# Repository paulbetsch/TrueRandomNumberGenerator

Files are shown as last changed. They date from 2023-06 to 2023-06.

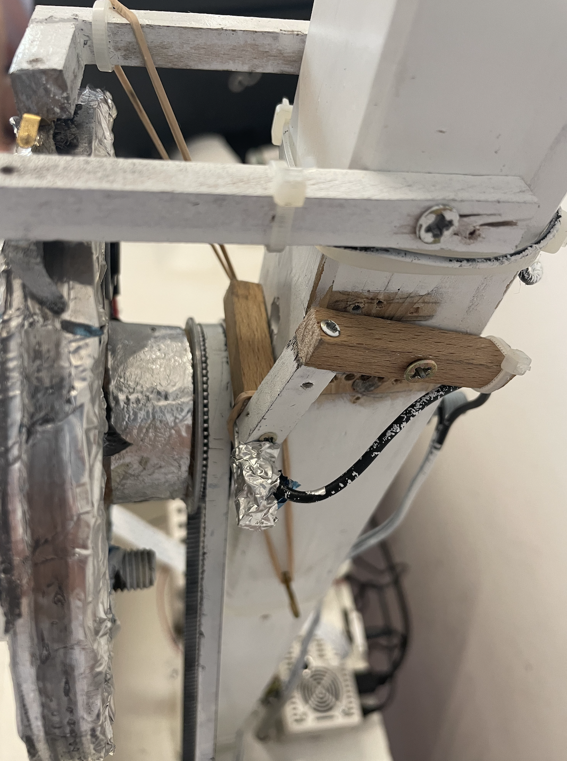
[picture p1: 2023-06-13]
TRNG_Pendel/Ressources/Construction/Pictures/Image20.jpeg

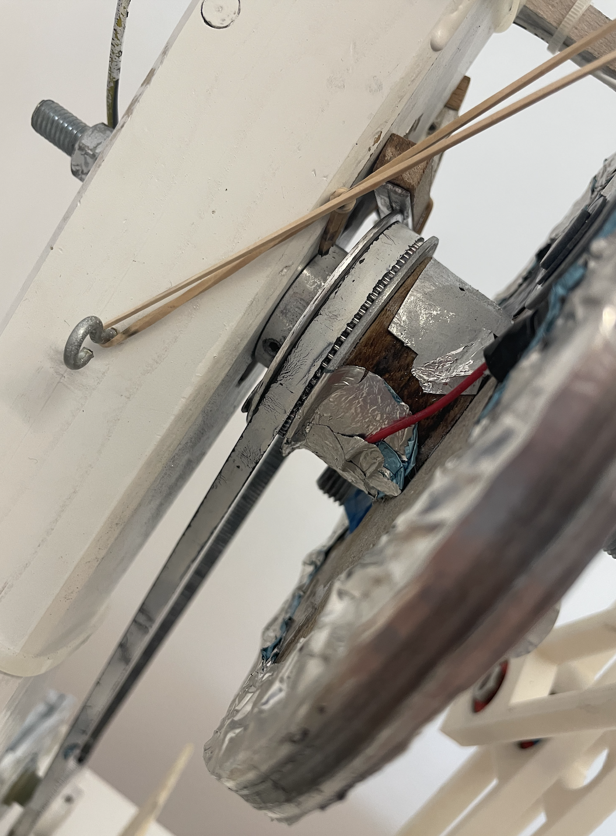
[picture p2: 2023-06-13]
TRNG_Pendel/Ressources/Construction/Pictures/Image18.jpeg

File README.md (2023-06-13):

# TRNG (True Random Number Generator)

## About
This repository includes all scripts and files which we use to develop a True Random Number Generator. There is a directory for each tool, we developed to help us. The whole Software solution can be found in the directory called "TRNG-Pendel".

## Requirements for setup
### Basic Setup:
- Tri Pendulum with a black square at the end of the thrid pendulum arm
- Raspberry Pi
- Raspberry Pi Camera Module
### Advanced Setup:
- Same components as for the basic setup and the following in addition:
- 12V electric motor
- 24V electric lifiting magnet
- Relay which can control up to 24V
- Jumper cables
- Power sources for motor, magnet and Raspberry Pi

## Requirements for Installation
- \>= [Python 3.9](https://www.python.org/downloads/release/python-390/)
- Any IDE you prefer, e. g. PyCharm, VS Code, Python IDE
- Git CLI to get the code onto the Raspberry Pi

## Installation
- use command : `git clone https://github.com/paulbetsch/TrueRandomNumberGenerator.git`
- than follow the instructions for [setting up the frontend](./FrontEnd/README.md)
- To setup the API follow these [instructions](./TRNG_API/README.md)
- When both servers are running and you can reach them you are ready to generate!

## Code Style
- Always **comment your code** with a short explanation of what it does.
- Make sure that at least one team member understand your comments.
- Global variables should be written in upper case with underlines instead of spaces e.g TEST_VARIABLE.
- Local variables should be written in camelCase.
- Function names should be written in PascalCase except the main function which is called: `__main__()`.
- If possible divide your code into multiple python files.
- If you have **multiple python files**, make sure you have **one start file**, which should be called `__init__.py`.
- Any other python files should be written in PascalCase excluding the start file.
- You have to **write a README.md file**, which explains everything/script/file contained in the directory.
- The code should always work **without any external Data**.
- All **filepaths must be relative**, so that the code works on every single PC.

## Team
- Carlo Bauer
- Paul Betsch
- Lukas Siegle
- Marina Göppel 
- Carsten Michel
-  Stefan Kleinhenz Leiva

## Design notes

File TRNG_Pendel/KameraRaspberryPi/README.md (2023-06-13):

# TRNG Live Image Capturing

## About
This repository includes code snippets, which we currently use on capturing live images from a RaspberryPi camera.

## Requirements
- These Scripts can only be run on the Raspberry Pi due to specific libraries

## Scripts
- __ObjectTracker__: The PendelManger class controls the interaction between the ObjectTracker and itself through shared variables. While a specific shared variable is set to true, the ObjectTracker continuously tracks black contours captured by a connected camera. If an error occurs during tracking, an error event is triggered and set as another shared variable, which can be accessed by the PendelManger. The PendelManger has the ability to set the first shared variable to false, effectively stopping the ObjectTracker. Additionally, the ObjectTracker generates random bits with the tracked Contours and writes them into a shared list with the PendelManger.

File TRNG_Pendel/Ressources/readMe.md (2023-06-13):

The files contained in this folder are 3D models for the TRNG. The files contain casings for a Raspberry Pi 3b+, anrelay, and a camera as well as a pendulum arm. The .stl files can be opened and edited with Autodesk Fusion 360. All models should be printed using pearl white PLA printing material.

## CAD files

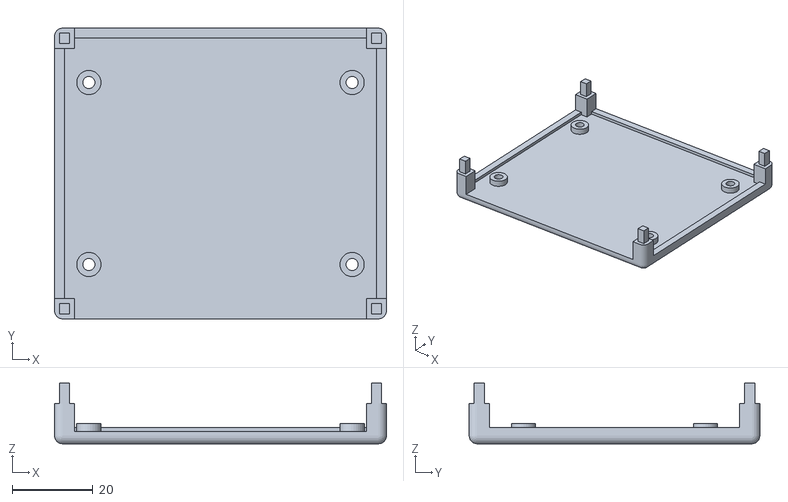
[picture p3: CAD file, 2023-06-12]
TRNG_Pendel/Ressources/3DModels/Relay_Mounting_Bottom.stl
82.1 x 71.9 x 15.0

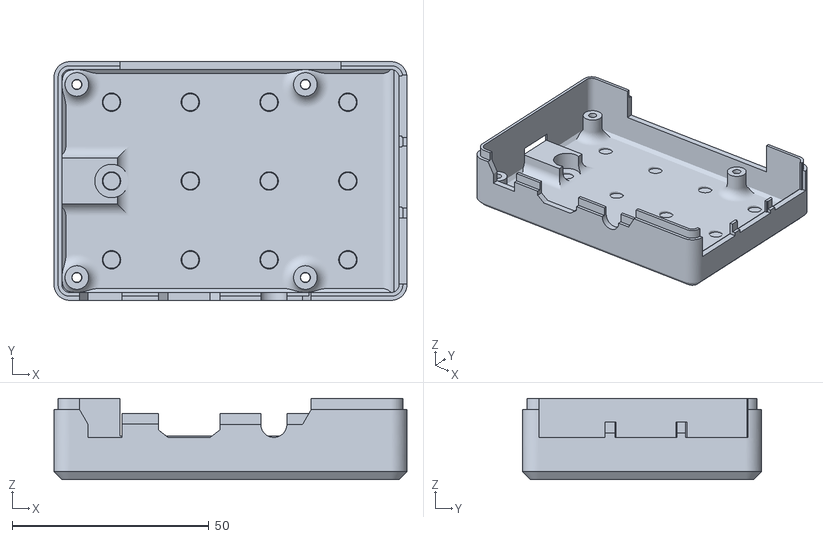
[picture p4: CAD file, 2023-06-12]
TRNG_Pendel/Ressources/3DModels/Raspberry_Pi_Mounting_Bottom.stl
89.6 x 60.6 x 20.6

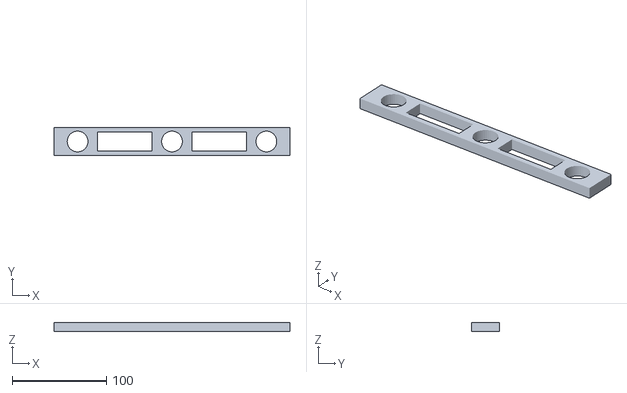
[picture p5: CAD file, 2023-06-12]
TRNG_Pendel/Ressources/3DModels/Pendulum_Arm.stl
250.0 x 30.0 x 10.0

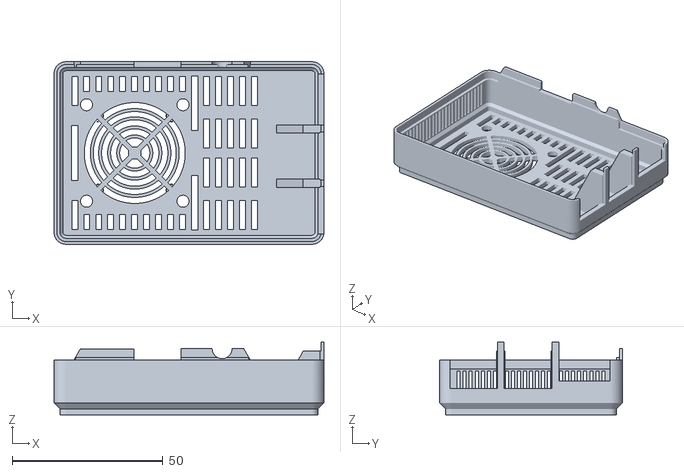
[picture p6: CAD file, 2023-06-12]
TRNG_Pendel/Ressources/3DModels/Raspberry_Pi_Mounting_Top.stl
89.6 x 60.6 x 24.2

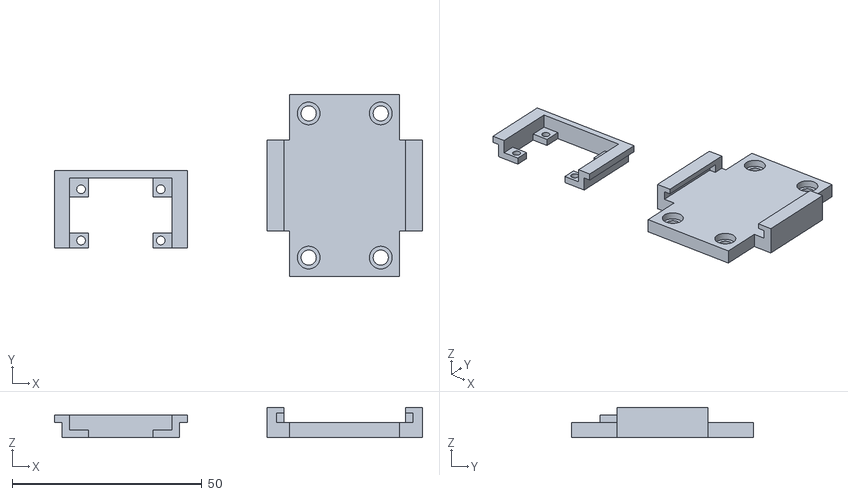
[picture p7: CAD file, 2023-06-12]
TRNG_Pendel/Ressources/3DModels/Camera_Mounting.stl
97.0 x 48.0 x 8.00

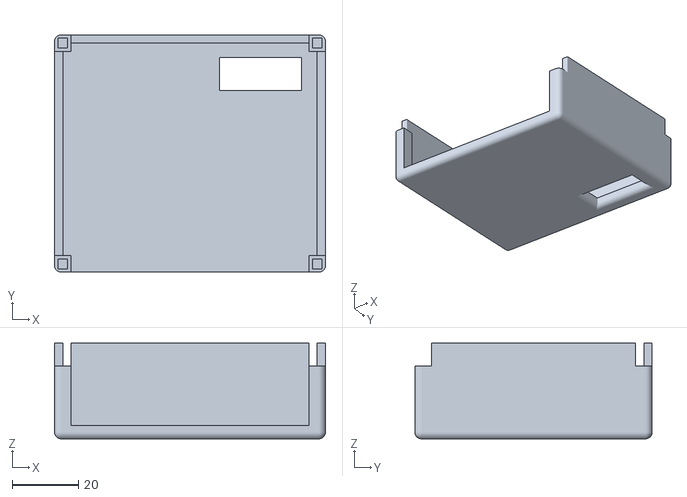
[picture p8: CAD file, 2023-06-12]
TRNG_Pendel/Ressources/3DModels/Relay_Mounting_Top.stl
82.1 x 71.9 x 29.0

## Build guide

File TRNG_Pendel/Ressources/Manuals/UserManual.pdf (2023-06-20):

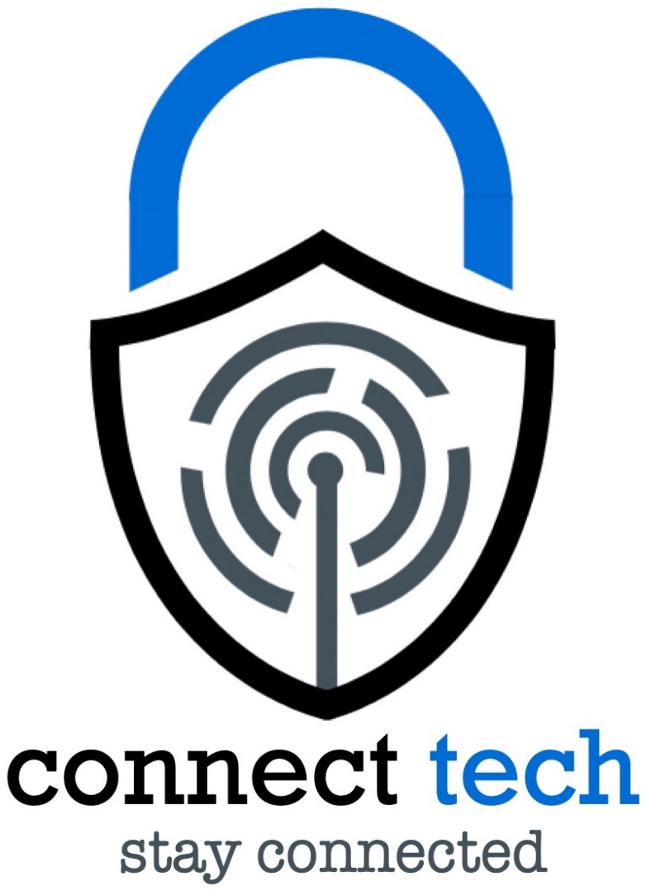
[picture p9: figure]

# User Manual Project Semester 2023

Carlo Bauer
Paul Betsch
Marina G¨oppel
Stefan Kleinhenz Leiva
Carsten Michel
Lukas Siegle

June 14, 2023

1

Project documentation

## Contents

1 Intended Use | 2
2 Usage | 3
3 Troubleshooting | 6

1

Project documentation

## 1 Intended Use

The intended use of this Pendulum is to be a True random bits Generator. A True random bits Generator uses a physical noise source to generate true random bits. The API allows for the reg-ulation of the number of bits the numbers should possess and the quantity in which they should be generated. The random bits can then be used for various applications, such as cryptography, simulation or scientific research.

This prototype of a True random bits Generator(TRNG) was invented and developed in the context of our project semester during the summer of 2023 at the University of Applied Science Mannheim.

### 1.1 Warnings

i. With this construction there is electricity in most parts. It is recommended to pull all power supplies before you work with or repair the prototype.

ii. All cables are lined with a cable conduit. Please refrain from taking them out and touching them.

iii. While the prototype is active the pendulum swings in a circular motion. Please stay at least 1m away from the pendulum to avoid getting hit.

iv. While the prototype is initialized, do not interfere in any way with the sampling process.

v. Please do not touch any cables or circuit boards integrated in the prototype.

vi. Use the prototype only with a good light setup to ensure no shadows are being captured by the camera. Shadows can massively interfere with the quality of the random bits.

2

Project documentation

## 2 Usage

### 2.1 General REST API Endpoints

This table covers various endpoints and their paths for accessing a random number generator in general. The random number generator produces HEX-encoded bit arrays as its output, with leading zeros added if necessary. To add leading zeros was explicitly wished by the client, we strongly advise against adding leading zeros to an hex-encoded random number in a normal context.

Endpoints | Path | Responses | Definition
GetRandomNums | /randomNum/getRandom | 200 | successful operation; HEX-encoded bit arrays (with leading zero if required)
| | 432 | system not ready; try init
| | 500 | data generation failed; check noise source
InitRandomNums | /randomNum/init | 200 | successful operation; random bits generator is ready and random bits can be requested
| | 409 | system already running
| | 500 | functionality not given; check hardware
| | 555 | unable to initialize the random bits generator within a timeout of 60 seconds
ShutdownRandomNums | /randomNum/shutdown | 200 | successful operation; random bits generator has been set to ’standby mode’
| | 409 | system already shutdown

### 2.2 How to use the REST API

A REST API allows different software applications to communicate and exchange data over the internet using standardized HTTP protocols. Our REST API provides all the necessary functionalities and logic responsible for the aforementioned requests and the initialization of the TRNG and its associated components.
To use the REST API you can choose a HTTP client of your choice e.g. Postman or Curl. In the following enumaration we explain how to interact with the API using Curl.
1. First of all it’s necessary to initialize the TRNG with the following command:

curl https://172.16.78.60:5520/trng/randomNum/init

3

Project documentation

2. If the request returns a status code 200 you can start generating random bits. To get random bits use following command:

curl https://172.16.78.60:5520/trng/randomNum/getRandom?quantity=16numBits=64

3. After you recieved your random bits it is possible to put the TRNG into standby mode by sending the following request:

curl https://172.16.78.60:5520/trng/randomNum/shutdown

### 2.3 Frontend

In order to have an easy access and control for the REST API, we have got as requirement to implement a frontend webpage. Accordingly, we have developed and implemented a user-friendly interface in order to access and interact with the REST-API´s functionalities.

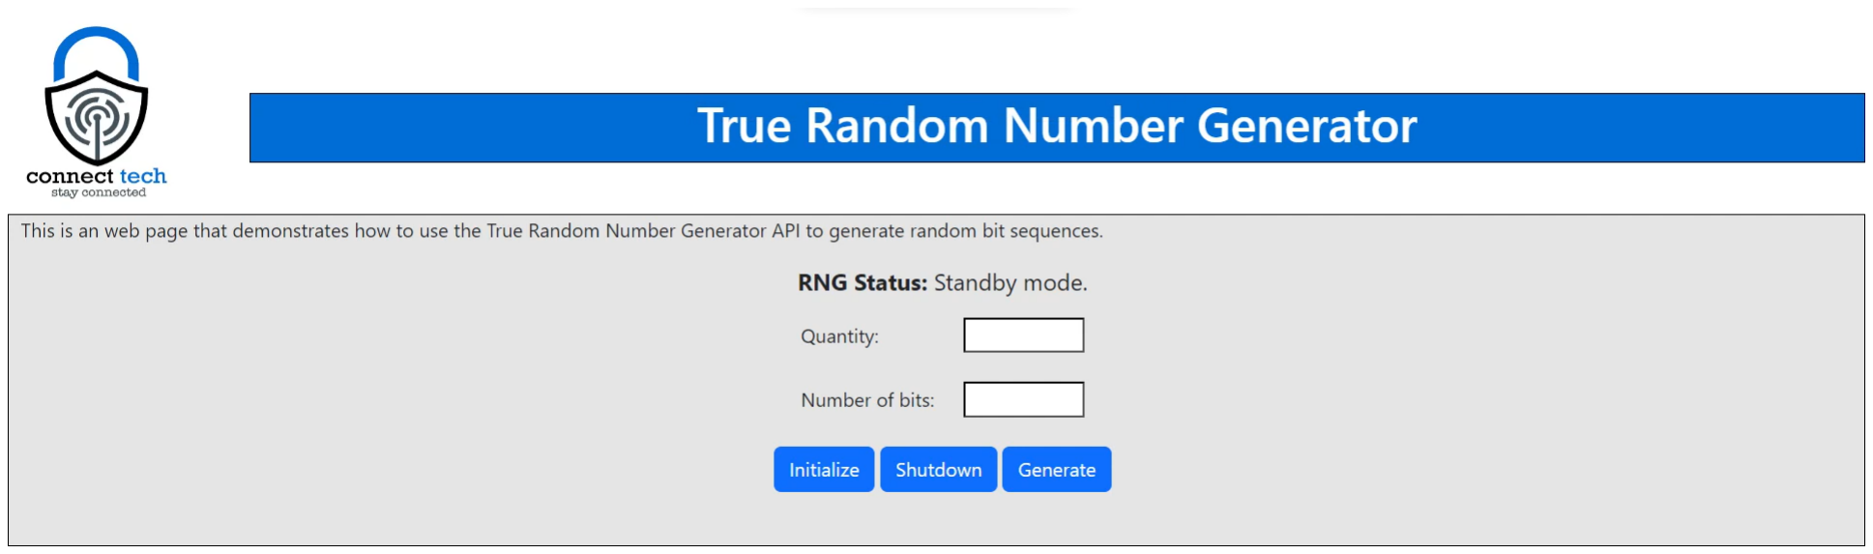
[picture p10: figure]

Figure 1: Webpage

- Quatity: This text box is intended for specifying the desired number of bits to be generated. It only accepts positive numbers as input.
- Number of bits: This text box is for specifying the length of the bits to be generated. It only accepts positive numbers as input.
- Initialize: This button is responsible for the aforementioned init request. Once the button is clicked, it will initialize the pendulum and its associated components.
- Shutdown: This button is responsible for the aforementioned shutdown request. Once the button is pressed, it will shut down the pendulum and its associated components.
- Generate: This button is responsible for initiating the getRandom request mentioned earlier. When the button is clicked, bits will be generated based on the input from two text boxes. The user can specify the desired number of bits and their desired length. Once the bits are generated, they will be displayed in a table format.

4

Project documentation

The RNG Status text provides the current state of the pendulum, indicating whether it is initialized, shut down, or generating bits.

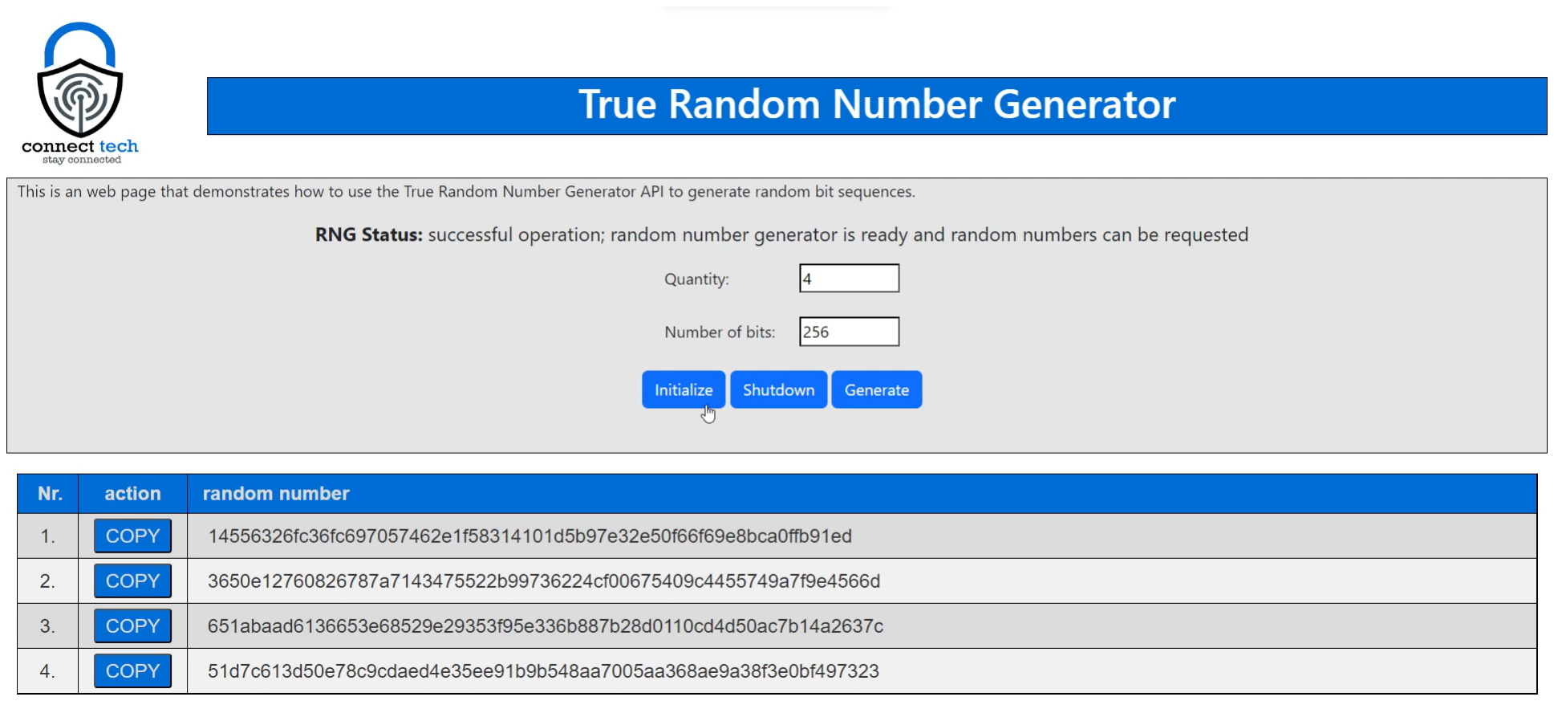
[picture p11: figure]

Figure 2: Webpage - Output example

5

Project documentation

## 3 Troubleshooting

Component | Problem | Solution
Magnet | Sliding contacts lost connection | Push contacts back on the tracks
| Sliding contact is defect | Exchange sliding contact
| Cable from Magnet to sliding tracks is defect | Glue back cable onto tracks
| Power supply is defect | Exchange power supply
| Lifting magnet is defect | Exchange magnet
Relay | Relay is defect | Unscrew cables and screw them back into place

Check connection between
relay and Raspberry Pi
Motor | Cables are loose | Reconnect cables
| Strap is broken | Exchange strap
| Strap is not in place | Put strap back in place
| None of the above worked | Check connection between relay and Raspberry Pi

Check power source
Exchange motor
Pendulum | Pendulum arm is broken | Exchange with 3D printed arm
Camera | No connection | Check cable on Raspberry Pi and on camera

Exchange camera

6

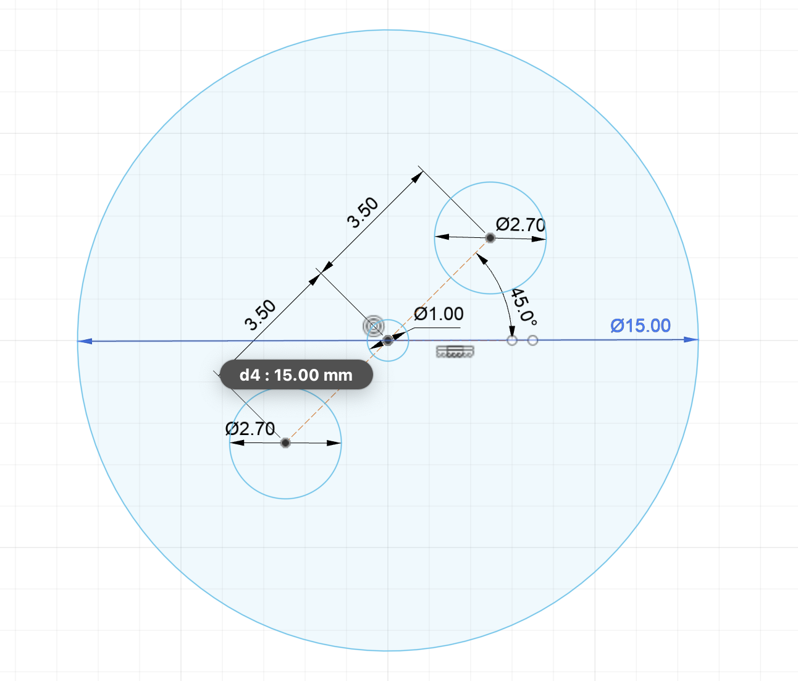
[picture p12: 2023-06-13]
TRNG_Pendel/Ressources/Construction/Pictures/Image3.jpeg

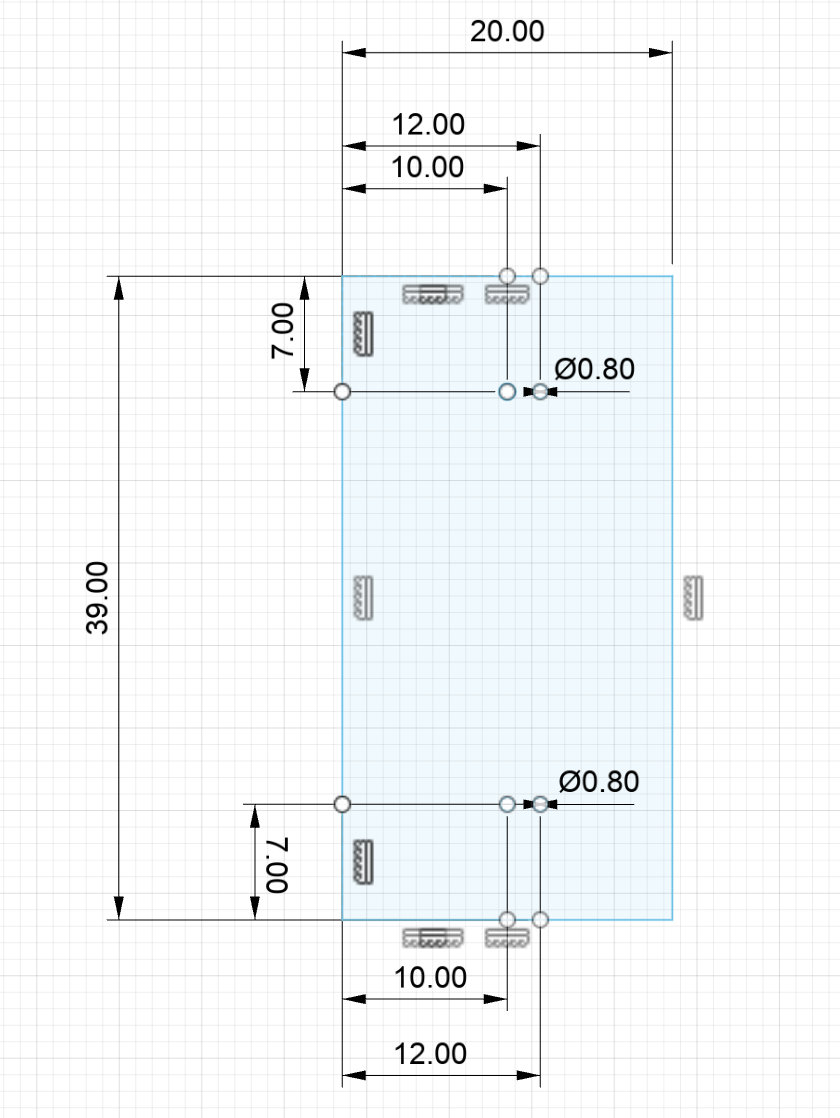
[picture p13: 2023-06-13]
TRNG_Pendel/Ressources/Construction/Pictures/Image2.jpeg

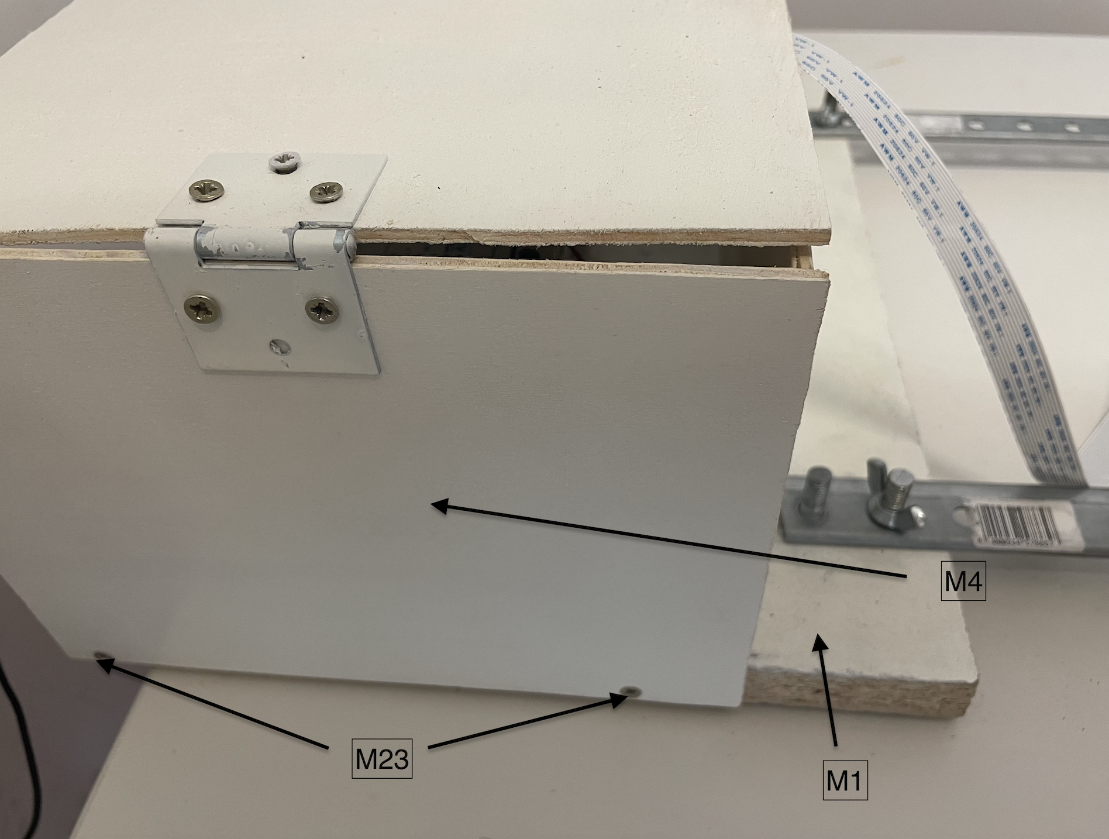
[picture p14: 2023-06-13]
TRNG_Pendel/Ressources/Construction/Pictures/Image24.jpeg

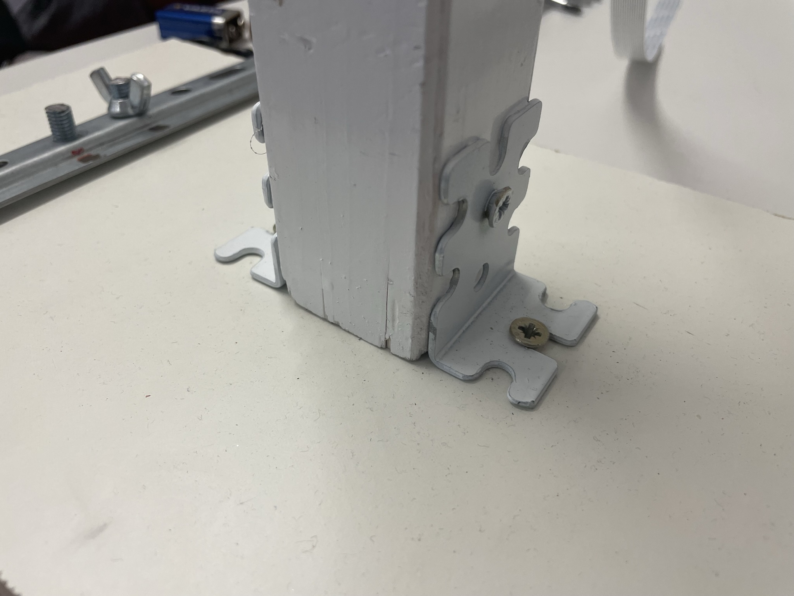
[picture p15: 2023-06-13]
TRNG_Pendel/Ressources/Construction/Pictures/Image5.jpeg

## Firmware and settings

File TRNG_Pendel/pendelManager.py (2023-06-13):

import sys, os

sys.path.append(os.path.dirname(os.path.abspath(__file__)))

import time
import RPi.GPIO as GPIO
from ErrorEvent import ErrorEvent
from multiprocessing import Process, Queue, Manager, Event, RawArray
from ctypes import c_char
from KameraRaspberryPi import ObjectTracker
import Tests.FunctionalityTestCamera as cameraFunc
import Tests.FunctionalityTestMagnet as magnetFunc
import Tests.StartUpTest as startUp
import Tests.OnlineTest as online
import Tests.TotalFailureTest as toft

BsiInitTestsPassed = None
__manager = None

# Die klasse sollte intern das multiprocessing verwalten
class PendelManager:
    def __init__(self):
        self.manager = Manager()
        pass
    
    def __cut_string(self, string, position, length):
        # Determine the start and end indices for slicing
        start_index = position
        end_index = position + length
        
        # Perform the string slicing
        cut_out_string = string[start_index:end_index]
        
        return cut_out_string

    def __prepareBinaryStringForReturn(self, binaryString, quantity, numBits):
        result = []
        numHexDigits = (numBits + 3) // 4
        
        position = 0
        # Get as many Random Numbers as required
        for i in range(0, quantity):
            # Get Random Bits from NoiseSource
            randomBits = self.__cut_string(binaryString, position, numBits)
            # Convert them into hex number
            randomHex = hex(int(randomBits, 2))
            # If necesarry remove leading "0x"
            hexStr = str(randomHex)[2:]
            # Prepend the necessary number of leading zeroes to the hex string
            hexStr = hexStr.zfill(numHexDigits)
            # Append the Hex Number to the array
            result.append(hexStr)
            # change position for next iteration:
            position += numBits
        return result

    def __hexArrayToBinaryString(self, hex_array):
        binaryString = ""

        for hex_string in hex_array:
            for hex_digit in hex_string:
                # Convert the hex digit to a 4-bit binary string
                decimal = int(hex_digit, 16) 
                binary_digit = bin(decimal)[2:]
                while(len(binary_digit) < 4):
                    binary_digit = '0' + binary_digit
                # Convert the binary digit string to a binary array
                binaryString += binary_digit
        
        return binaryString

    # Wird später aufgerufen um die Funktionalität der Lichtschranke, der Kamera und der Motorisierung des Pendels zu gewährleisten.
    def checkFunctionality(self):
        global BsiInitTestsPassed
        BsiInitTestsPassed = False
        # Check if all components are ready to work
        # Only functional if all components function correctly
        if(cameraFunc.CheckCameraFunctionality() and magnetFunc.CheckMagnetFunctionality()):
            # Check if noise source works correctly
            hexNums = self.generateRandomBits(10, 100)
            # convert hexNums to binary
            binaryData = self.__hexArrayToBinaryString(hexNums)
            BsiInitTestsPassed = self.checkBSITests(binaryData)
        else:
            BsiInitTestsPassed = False
        return BsiInitTestsPassed
    # Hier soll der Motor gesteuert werden, und die Werte der Kamera und der Lichtschranke ausgewertet werden
    # Aktuell zu Testzwecken werden hier nur pseudozufallszahlen generiert
    def generateRandomBits(self, quantity, numBits):
        #resultArray which will be returned
        result = []
        
        self.manager = Manager()
        
        with self.manager as m:
            # Shared Memory for Random Bits
            randomValues = Queue()
            stopEvent = Event()
            errorEvent = ErrorEvent(RawArray(c_char, 255))
            # Start the generation of random values
            videoProc = Process(target=ObjectTracker.CapturePendelum, args=(stopEvent, errorEvent, randomValues))
            videoProc.start()
            # Do checks with numbers and generate as much as the params require here
            bits = ""
            goodBytes = ""
            failCounter = 0
            checkedBefore = False

            # As long as the objectTracker has no errors, we can sample further data
            # The ObjectTracker.py is only allowed to stop the Generationprocess if any errors happen.
            while not errorEvent.isEventSet():

                # If eight times a byte or more are in the Queue we want to sample them
                if(randomValues.qsize() >= 8):
                    # Transfer eight objects over multiprocess communication from the ObjectTracker.py to pendelManager.py
                    for i in range(0, 8):
                        bits += randomValues.get()
                    # 128 bytes = 1024 bits have been transfered to the pendelManager, the quality of the bits is checked with the 
                    # Tests explained in PTG.2. provided by the BSI in Germany.
                    if(len(bits) >= 1024): 
                        if(checkedBefore):
                            # If the random bits out of the iteration before have passed the Online Tests.
                            # It is very likely that the next 1024 bits are also randoms.
                            # Therefore we will take the next 1024 and prepare it for the output
                            goodBytes += bits
                            print("goodBits" + str(len(goodBytes)))
                            checkedBefore = False
                        elif(online.onlineTest(bits)):
                            checkedBefore = True
                            failCounter = 0
                        elif(failCounter < 3):
                            failCounter += 1
                        else:
                            # If the Tests fail ten times in a row, the probality of an error in the samplingprocess is very high.
                            # Therefore the generationprocess is stopped and the API will provide an statuscode providing further information                        elif(failCounter + 1 == 10):
                            errorEvent.setErrorDescription("Online Test has failed 3 Times in a row")
                            errorEvent.setEvent()
                        bits = ""

                    # If the requested amount of bits has been reached, the generation process will be stopped and the stopEvent will be triggerd
                    if(len(goodBytes) >= (quantity * numBits)):
                        # Reset Lifting Magnet to prevent overheating
                        GPIO.output(13,1)
                        # Stop the generation of random values
                        stopEvent.set()
                        break
                else:
                    # polling rate at 0.1 seconds for main process
                    time.sleep(0.1)
            
            # ErrorEvent handling
            if(errorEvent.isEventSet()):
                stopEvent.set()
                raise Exception(errorEvent.getErrorDescription())
            else:
                pass

            #prepare goodByts for return (split into quantitty times numBits and change to hex numbers)
            result = self.__prepareBinaryStringForReturn(goodBytes, quantity, numBits)

            # End Process
            videoProc.terminate()

        return result

    # Statische Prüfung der Zufallszahlen
    def checkBSITests(self, binaryData):
        return toft.TotalFailureTest(str(binaryData), False, 8) and startUp.StartUpTest(str(binaryData))

# Returns the only instance of the PendelManger class
def GetInstance():
    return __manager

# Wir können feststellen ob der Manager direkt gestartet wird
if __name__ == '__main__':
    if(__manager == None):
        __manager = PendelManager()

    # For Testing:
    functional = __manager.checkFunctionality()
    if(functional):   
        print("Functional") 
        print(__manager.generateRandomBits(4, 256))
    else:
        print("Not Functional")

# oder ob er von der API aus aufgerufen wird.            
else:
    if(__manager == None):
        __manager = PendelManager()

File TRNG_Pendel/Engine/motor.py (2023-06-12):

import RPi.GPIO as GPIO
from time import sleep    
import time

# This methode allows to control the electric motor and the lifting magnet to power the pendulum.
# durationRunning: Time the motor and lifting magnet should run
def StartEngine(durationRunning, timeToWait):
    GPIO.setwarnings(False)
    GPIO.setmode(GPIO.BCM) 
    
    # Configure Pin 6 & 13 as output that we can send digital 1 and 0 over this pins.
    # Pin 6 is connected to the relay and can toggle the circuit for the electric motor
    # Pin 13 toggles the circuit for the lifting magnet
    GPIO.setup(6, GPIO.OUT)  
    GPIO.setup(13, GPIO.OUT)  
    
    GPIO.output(6,0)
    GPIO.output(13,0)
    # Sleeps for the provided amount of time. While sleeping the motor is running
    sleep(durationRunning) 
    
    # Break the circuit for the relay modules for electric motor & lifting magnet
    GPIO.output(6,1)   
    GPIO.output(13,1) 

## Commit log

2023-04-03 Added README.md to Z-Diode
2023-04-04 Update ReadThePendulum.py
    Current Code
2023-04-20 Python Skript Raspberry Pi Kamera
2023-04-24 Lsb Sampler added
2023-04-28 Lsb Sampler to txt File
2023-04-28 shotdown und init request implementiert
2023-04-28 Gerüst GUI und init Dateien
2023-04-29 font size, und color
2023-05-02 kommentare ergänzt und imports
2023-05-02 Update Code Style und README
2023-05-02 Code Style und Kommentare
2023-05-02 Power Off when Process is closed
2023-05-02 Update ObjectTracker.py
    ObjectTracker current copde
2023-05-02 Start und Stop Methoden für die Tools angepasst
2023-05-03 Create controls.py
    These are the controls for the motor and magnete
2023-05-04 Erwartungswert skript und Pendelmanager
2023-05-08 Added functionality Test for Camera Module
2023-05-08 Neueste Version des ObjectTrackers + updated README.md + kleine Änderung am functionality Test
2023-05-09 Bug Fixes Functionality Test Camera
    [FunctionalityTestCamera.py]
2023-05-10 Pendelanalyse Skript kommentiert und aufgeräumt
2023-05-11 Update ObjectTracker.py
    Current Version (cleaned) only range Method
2023-05-11 Altes Erwartungsraumskript wiederhergestellt und neues kommentiert
2023-05-11 Read.Me added & changed ObjectTracker to use motorControl function by importing the other module
2023-05-12 fixed errors when running startuptest
    [StartUpTest.py]
2023-05-15 Alle Bilder erzeugt und nochmals verbessert
2023-05-19 Online Tests ausführbar und prozedural
2023-05-19 Online Test without prints
2023-05-22 Bug Fixing in PendelManager
    [pendelManager.py]
2023-05-23 Updated API for custom ErrorEvent and Timeout for 60s
    [pendelManager.py]
2023-05-25 Latest Code Version from Raspberry Pi; PendelManager works
2023-05-25 Added Functionality Test for Lifting Magnet
2023-06-07 Current working code on raspberrypi
2023-06-12 Add files via upload
    3D Druck STL Dateien
    [Camera_Mounting.stl, Pendulum_Arm.stl, Raspberry_Pi_Mounting_Bottom.stl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]
2023-06-12 current working code base from raspberry pi
2023-06-13 RaspberryPi working Code with missing Certificates
    [FunctionalityTestCamera.py, FunctionalityTestMagnet.py, ObjectTracker.py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]
2023-06-13 Code from production system
    [Camera_Mounting.stl, Pendulum_Arm.stl, Raspberry_Pi_Mounting_Bottom.stl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]
2023-06-13 Documentation Data added
    [Camera_Mounting.stl, Pendulum_Arm.stl, Raspberry_Pi_Mounting_Bottom.stl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]
